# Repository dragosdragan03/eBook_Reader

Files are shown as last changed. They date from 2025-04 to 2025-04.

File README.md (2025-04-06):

# OpenBook ESP32-C6 Pin Connections

This document describes the pin connections between the ESP32-C6-WROOM-1 module and the various peripherals in the OpenBook e-reader project.

## Project Overview

The OpenBook is an electronic reader device based on the ESP32-C6 microcontroller. It features an e-paper display, SD card storage, environmental sensing, and robust power management for extended battery life. The device was designed to provide a power-efficient reading experience with modern wireless connectivity capabilities.

## Hardware Overview

### Main Controller – ESP32-C6-WROOM-1-N8
- **Architecture**: RISC-V (Single-Core)
- **Wireless**: Wi-Fi 6, Bluetooth 5 LE
- **Operating Voltage**: 3.3V
- **Interfaces**: SPI, I²C, UART, GPIO, USB

## Pin Assignments

| ESP32-C6 Pin | Function | Connected To | Description |
|---|---|---|---|
| 3 | RESET | Reset Button | System hardware reset |
| 4 | SS_SD | SD Card (pin 2) | SPI Slave Select for SD card |
| 6 | SCK | SD Card (pin 5) | SPI Clock signal |
| 7 | MOSI | SD Card (pin 3) | SPI Master Out Slave In |
| 8 | INT_RTC | RTC Module (pin 3) | Interrupt signal from RTC |
| 9 | 32KHz | RTC Module (pin 1) | 32KHz clock signal from RTC |
| 13 | USB_D- | USB-C Connector (pin 3) | USB Data Negative line |
| 14 | USB_D+ | USB-C Connector (pin 1) | USB Data Positive line |
| 15 | IO/BOOT | Boot Button | Boot mode selector button |
| 16 | RTC_RST | RTC Module (pin 4) | RTC reset control |
| 17 | I2C_PW | BME688 Sensor (pins 6, 8, 2) | Power control for environmental sensor |
| 19 | SDA | Multiple I²C devices | I²C Serial Data line (shared) |
| 20 | SCL | Multiple I²C devices | I²C Serial Clock line (shared) |
| 23 | IO/CHANGE | Change Button | Display/Mode change button |
| 27 | MISO | SD Card (pin 7) | SPI Master In Slave Out |

## Storage & Display

### SD Card
- **Interface**: SPI
- **Pins**:
  - CS (SS_SD): `GPIO 4`
  - MOSI: `GPIO 7`
  - MISO: `GPIO 27`
  - SCK: `GPIO 6`
- **Storage Capacity**: Supports up to 32GB SDHC

### E-Paper Display
- **Interface**: SPI (shared with SD)
- **Pins**:
  - CS (EPD_CS): `GPIO 10`
  - DC (EPD_DC): `GPIO 5`
  - RESET: `GPIO 23`
  - BUSY: `GPIO 3`
  - MOSI / SCK: shared with SD
- **Resolution**: 1404 × 1872 pixels (6.8")

### External NOR Flash (64MB)
- **Interface**: SPI (shared)
- **Pins**:
  - CS (FLASH_CS): `GPIO 12`
  - Shared: `MOSI`, `MISO`, `SCK`

## Timekeeping & Sensors

### RTC – DS3231SN
- **Interface**: I²C
- **Pins**:
  - SCL: `GPIO 20`
  - SDA: `GPIO 19`
  - INT: `GPIO 8`
  - 32KHz: `GPIO 9`
  - RESET: `GPIO 16`

### Environmental Sensor – BME688
- **Interface**: I²C (shared with RTC)
- **Supply Voltage**: 3.3V
- **Power Control Pin**: `GPIO 17`
- **Measurements**: Temperature, humidity, pressure, gas

## Power Management

### Power Supply
- **Input**: USB-C (5V)
- **Output**: 3.3V via LDO regulator
- **Battery**: 3.7V Li-Po, 2000mAh

### Charging Circuit
- **Function**: Li-Po battery charging
- **Charging Current**: 500mA
- **Battery Monitoring**:
  - Fuel gauge via I²C (MAX17048)
  - Pins: Same as shared I²C bus

## Communication & Interfaces

### USB-C Connector
- **Data Pins**:
  - USB_D-: `GPIO 13`
  - USB_D+: `GPIO 14`

### Qwiic / Stemma QT Connector
- **Interface**: I²C
- **Voltage**: 3.3V
- **Pins**: Shared with main I²C bus

## User Inputs
- **BOOT Button**: `GPIO 15`
- **RESET Button**: connected to pin 3
- **CHANGE Button**: `GPIO 23`

## Protection Features
- TVS diodes on USB data lines and SPI lines
- Reverse polarity protection
- ESD protection

## Components BOM (Bill of Materials)

| Component | Link | Estimated Price |
|---|---|---|
| CHG_LED | [KP-1608SURCK - Kingbright](https://www.snapeda.com/parts/KP-1608SURCK/Kingbright/view-part/?ref=search&t=LED%200603) | €0.15 |
| SJ1 | [Solder Jumpers](https://grabcad.com/library/solder-jumpers-1) | €0.05 |
| R3 | [R0402 1% 100K (RC0402FR-07100KL) - YAGEO](https://componentsearchengine.com/part-view/R0402%201%25%20100%20K%20(RC0402FR-07100KL)/YAGEO) | €0.01 |
| R1_PWRUSB | [R0402 1% 100K (RC0402FR-07100KL) - YAGEO](https://componentsearchengine.com/part-view/R0402%201%25%20100%20K%20(RC0402FR-07100KL)/YAGEO) | €0.01 |
| C1, C2, C4_USB, C6, C7, C8, C9, C10, C_DELAY | [CC0402MRX5R5BB106 - YAGEO](https://componentsearchengine.com/part-view/CC0402MRX5R5BB106/YAGEO) | €0.10 (per unit) |
| C3 | [Link 3D model](https://a360.co/4iZy6AA) | €0.12 |
| R1_PINH1, R2-PINH1, R_BOOT, R_CHARGE, R_CL1, R_RESET | [R0402 1% 100K (RC0402FR-07100KL) - YAGEO](https://componentsearchengine.com/part-view/R0402%201%25%20100%20K%20(RC0402FR-07100KL)/YAGEO) | €0.01 (per unit) |
| R1, R1-PINH, R2-PINH, R4, R5, R6, R7, R8, R9, R10 | [R0402 1% 100K (RC0402FR-07100KL) - YAGEO](https://componentsearchengine.com/part-view/R0402%201%25%20100%20K%20(RC0402FR-07100KL)/YAGEO) | €0.01 (per unit) |
| J4 | [Store Comet SRL](https://store.comet.srl.ro/Catalogue/Product/43497/) | €0.35 |
| R_CAPACITOR | [R0402 1% 100K (RC0402FR-07100KL) - YAGEO](https://componentsearchengine.com/part-view/R0402%201%25%20100%20K%20(RC0402FR-07100KL)/YAGEO) | €0.01 |
| C5 | [CC0402MRX5R5BB106 - YAGEO](https://componentsearchengine.com/part-view/CC0402MRX5R5BB106/YAGEO) | €0.10 |
| EPD_C1, EPD_C2, EPD_C5, EPD_C6, EPD_C7, EPD_C8, EPD_C9, EPD_C10, EPD_C11, EPD_C12 | [CC0402MRX5R5BB106 - YAGEO](https://componentsearchengine.com/part-view/CC0402MRX5R5BB106/YAGEO) | €0.10 (per unit) |
| R2 | [R0402 1% 100K (RC0402FR-07100KL) - YAGEO](https://componentsearchengine.com/part-view/R0402%201%25%20100%20K%20(RC0402FR-07100KL)/YAGEO) | €0.01 |
| R1_BAT | [R0402 1% 100K (RC0402FR-07100KL) - YAGEO](https://componentsearchengine.com/part-view/R0402%201%25%20100%20K%20(RC0402FR-07100KL)/YAGEO) | €0.01 |
| Q1, Q3 | [SI1308EDL-T1-GE3 - Vishay](https://componentsearchengine.com/part-view/SI1308EDL-T1-GE3/Vishay) | €0.45 (per unit) |
| R2_BAT | [R0402 1% 100K (RC0402FR-07100KL) - YAGEO](https://componentsearchengine.com/part-view/R0402%201%25%20100%20K%20(RC0402FR-07100KL)/YAGEO) | €0.01 |
| C1_BAT, C1_BAT1, C1_BAT2, C2_BAT, C5_USB | [CC0402MRX5R5BB106 - YAGEO](https://componentsearchengine.com/part-view/CC0402MRX5R5BB106/YAGEO) | €0.10 (per unit) |
| C4 | [CC0402MRX5R5BB106 - YAGEO](https://componentsearchengine.com/part-view/CC0402MRX5R5BB106/YAGEO) | €0.10 |
| R2-USB, R2-USB1 | [R0402 1% 100K (RC0402FR-07100KL) - YAGEO](https://componentsearchengine.com/part-view/R0402%201%25%20100%20K%20(RC0402FR-07100KL)/YAGEO) | €0.01 (per unit) |
| L1 | [744043680 - Wurth Elektronik](https://eu.mouser.com/ProductDetail/Wurth-Elektronik/744043680?qs=PGXP4M47uW6VkZq%252BkzjrHA%3D%3D) | €0.85 |
| IC1 | [BD5229G-TR - ROHM Semiconductor](https://componentsearchengine.com/part-view/BD5229G-TR/ROHM%20Semiconductor) | €1.20 |
| BOOT_BUTTON, CHANGE_BUTTON, RESET_BUTTON | [EVQP7L01P - Panasonic](https://www.snapeda.com/parts/EVQP7L01P/Panasonic/view-part/?ref=search&t=evqp7l) | €0.25 (per unit) |
| C10_SUPERCAP | [CPH3225A - Seiko Instruments](https://www.snapeda.com/api/url_track_click_mouser/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) | €2.50 |
| U3 | [DS3231SN - Analog Devices](https://www.snapeda.com/api/url_track_click_mouser/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) | €8.95 |
| U2 | [ESP32-C6-WROOM-1-N8 - Espressif](https://www.snapeda.com/parts/ESP32-C6-WROOM-1-N8/Espressif+Systems/view-part/?ref=eda) | €4.50 |
| PFMF.050.1 | [B72520T0350K062 - EPCOS-TDK](https://www.mouser.co.uk/ProductDetail/EPCOS-TDK/B72520T0350K062?qs=dEfas%2FXlABIszF52uu7vrg%3D%3D) | €0.65 |
| D2, D7 | [SD0805S020S1R0 - KYOCERA-AVX](https://eu.mouser.com/ProductDetail/KYOCERA-AVX/SD0805S020S1R0?qs=jCA%252BPfw4LHbpkAoSnwrdjw%3D%3D) | €0.30 (per unit) |
| SENSOR2 | [BME680 - Bosch](https://www.snapeda.com/parts/BME680/Bosch/view-part/?welcome=home) | €10.50 |
| MCP73831 | [MCP73831T-2ACI-OT - Microchip](https://www.digikey.ro/en/products/detail/microchip-technology/MCP73831T-2ACI-OT/964301) | €0.75 |
| J1 | [XC6220A331MR-G - Torex](https://componentsearchengine.com/part-view/XC6220A331MR-G/Torex) | €1.25 |
| U4 | [MAX17048G+T10 - Analog Devices](https://www.snapeda.com/api/url_track_click_mouser/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) | €3.80 |
| D3, D4, D5 | [MBR0530 - ON Semiconductor](https://www.snapeda.com/api/url_track_click_mouser/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) | €0.40 (per unit) |
| D6, D8, D9, D10, D11, D12 | [PGB1010603MR - Littelfuse](https://www.snapeda.com/api/url_track_click_mouser/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) | €0.30 (per unit) |
| J3 | [Model Link - DigiKey](https://www.digikey.ro/en/models/926710) | €1.05 |
| J2 | [USB4110-GF-A - GCT](https://componentsearchengine.com/part-view/USB4110-GF-A/GCT%20(GLOBAL%20CONNECTOR%20TECHNOLOGY)) | €0.95 |
| Q2 | [DMG2305UX-7 - Diodes Inc](https://componentsearchengine.com/part-view/DMG2305UX-7/Diodes%20Incorporated) | €0.55 |
| TP1, TP2, TP3, TP4, TP5, TP6, TP7, TP8, TP9, TP10, TP11, TP12, TP13, TP14, TP15, TP16, TP17 | [Test Points PCB](https://grabcad.com/library/test-points-printed-circuit-board-1) | €0.02 (per unit) |
| D1 | [USBLC6-2SC6Y - STMicroelectronics](https://www.snapeda.com/parts/USBLC6-2SC6Y/STMicroelectronics/view-part/?ref=eda) | €0.60 |
| U1 | [W25Q512JVEIQ - Winbond](https://www.snapeda.com/parts/W25Q512JVEIQ/Winbond+Electronics/view-part/?ref=eda) | €4.20 |
| IC4 | [XC6220A331MR-G - Torex](https://componentsearchengine.com/part-view/XC6220A331MR-G/Torex) | €1.25 |

## Circuit Block Diagram
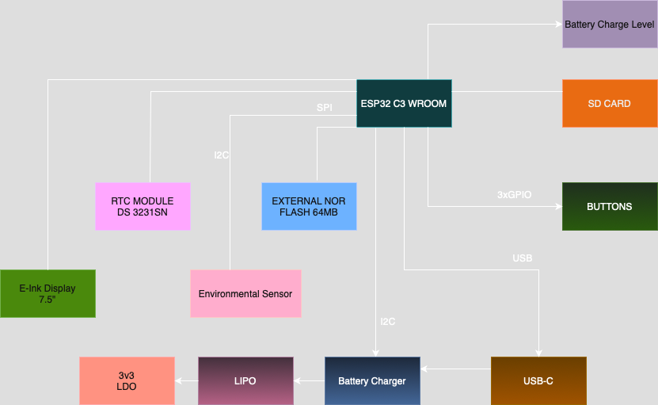
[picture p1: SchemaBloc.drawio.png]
Circuit Block Diagram


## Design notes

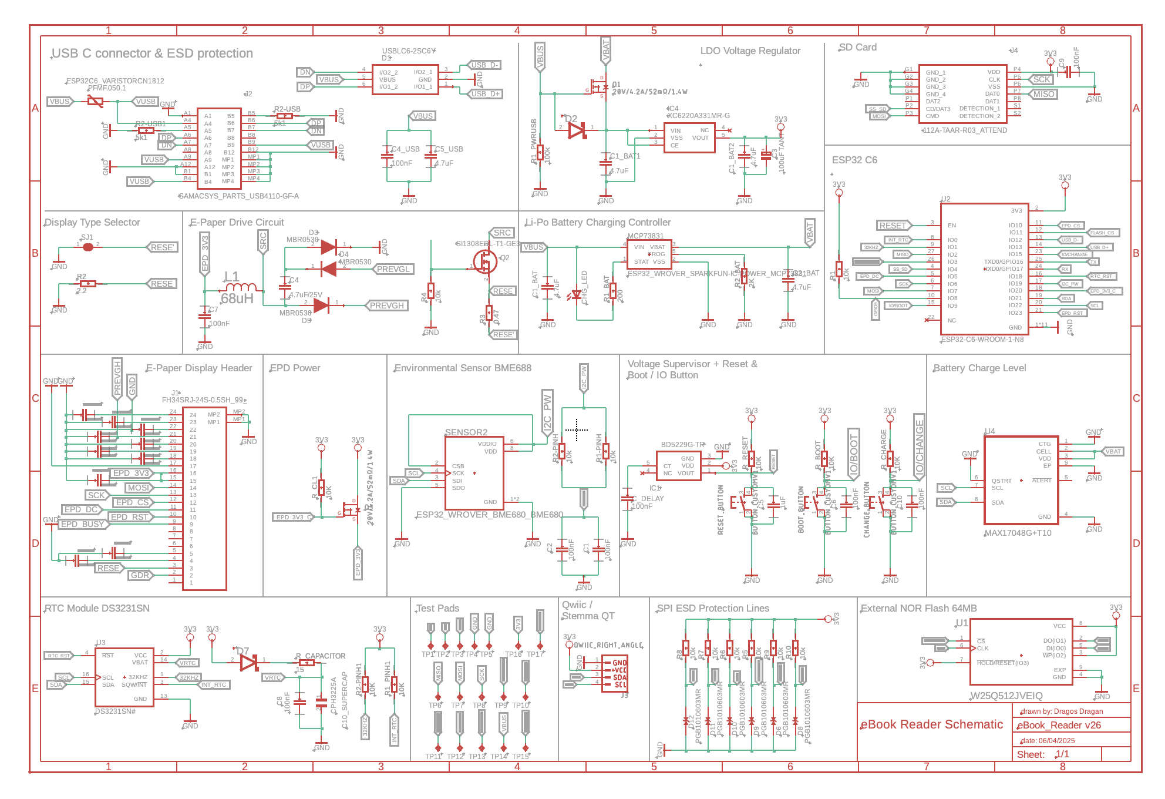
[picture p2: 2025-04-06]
Images/Schematic.png

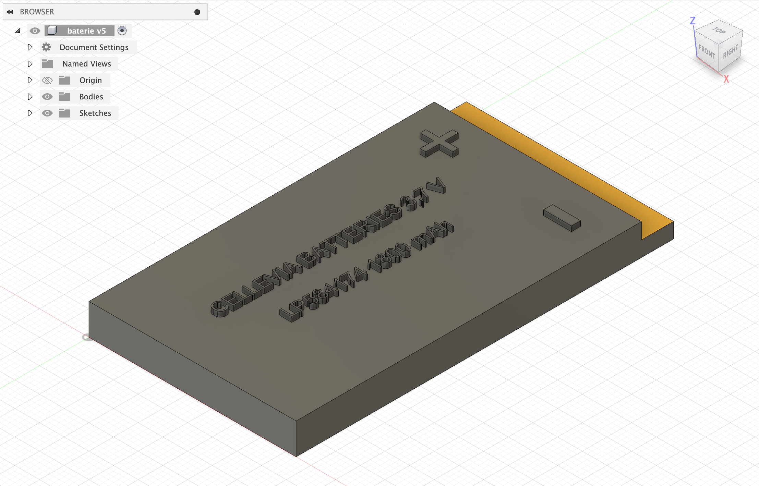
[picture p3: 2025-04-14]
Images/Battery.png

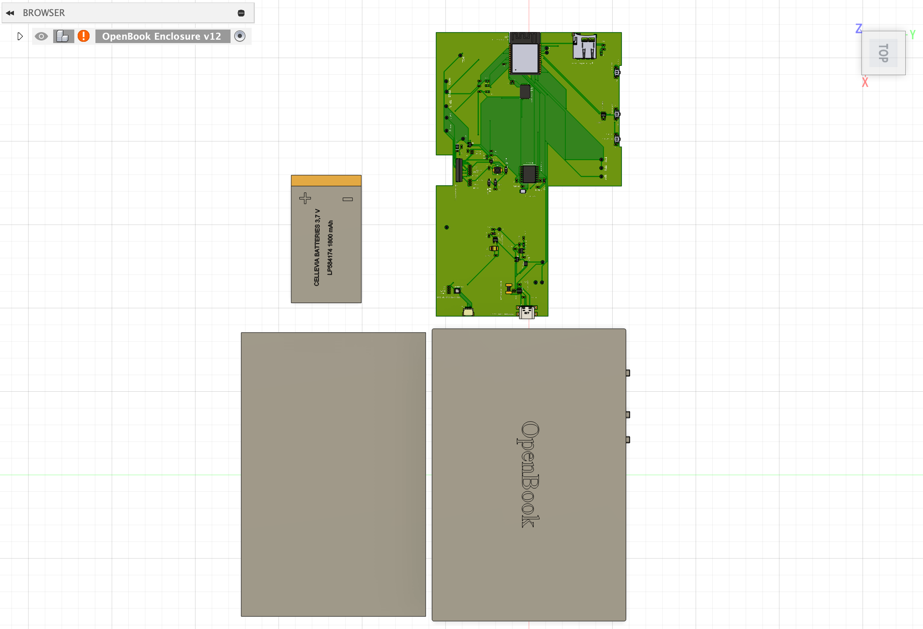
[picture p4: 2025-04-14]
Images/PCB+Box+Battery+Display_1.png

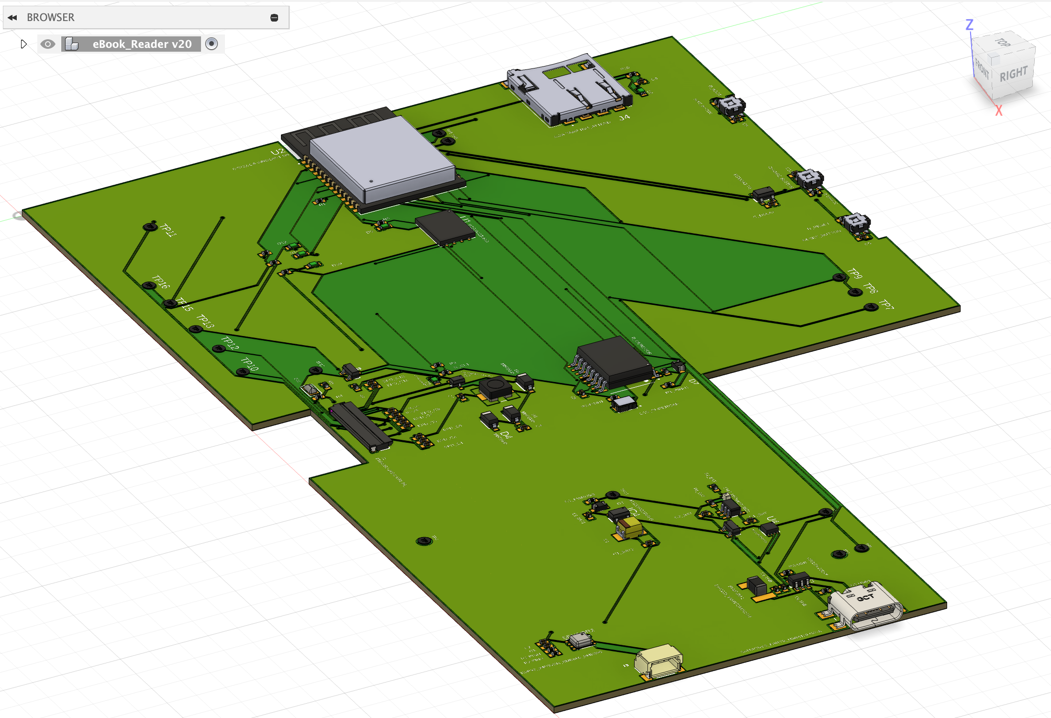
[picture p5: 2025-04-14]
Images/PCB.png

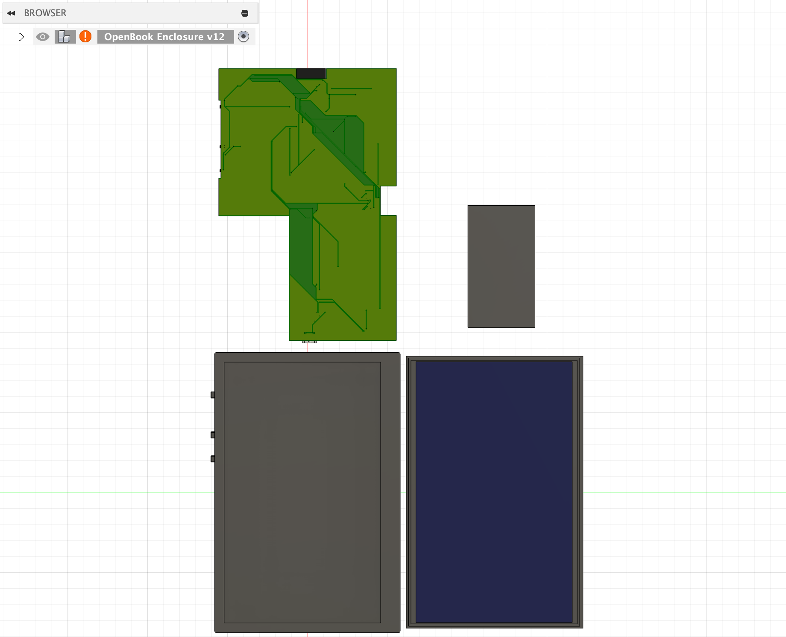
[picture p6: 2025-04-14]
Images/PCB+Box+Battery+Display_2.png

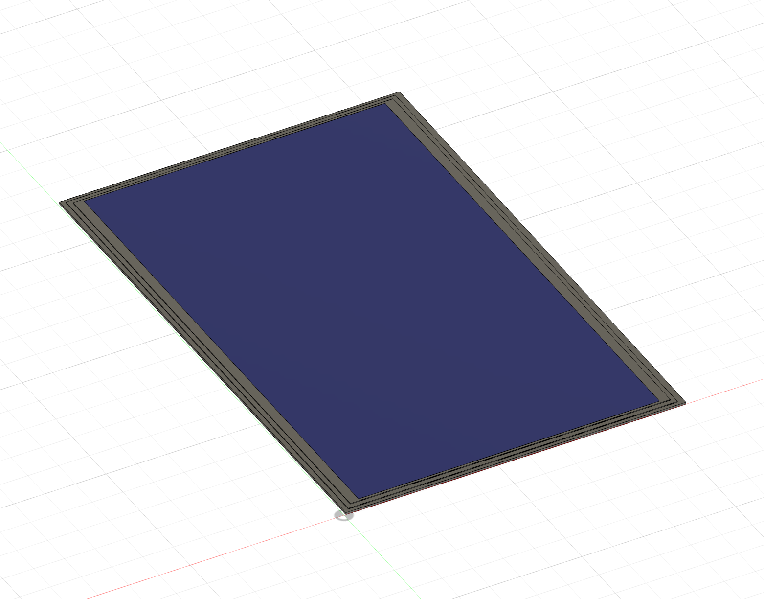
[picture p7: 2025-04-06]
Images/Display.png

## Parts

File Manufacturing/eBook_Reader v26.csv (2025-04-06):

Qty | Value | Device | Package | Parts | Description | ARROW_PART_NUMBER | ARROW_PRICE-STOCK | AVAILABILITY | CENTROID_NOT_SPECIFIED | CHECK_PRICES | COPYRIGHT | DATASHEET | DESCRIPTION | DIGIKEY_DESCRIPTION | DIGIKEY_PART_NUMBER | HEIGHT | LEAD_FREE | MANUFACTURER_NAME | MANUFACTURER_PART_NUMBER | MF | MFR_NAME | MOUSER_PART_NUMBER | MOUSER_PRICE-STOCK | MOUSER_TESTING_PART_NUMBER | MOUSER_TESTING_PRICE-STOCK | MP | MPN | PACKAGE | POPULARITY | PREFIX | PRICE | PROD_ID | PURCHASE-URL | ROHS | SNAPEDA_LINK | SPICEMODEL | SPICEPREFIX | TEMPERATURE_RANGE_HIGH | TEMPERATURE_RANGE_LOW | TP_SIGNAL_NAME | VALUE
1 |  | ADAFRUIT_LEDCHIP-LED0603 | ADAFRUIT_CHIP-LED0603 | CHG_LED | LED |  |  |  |  |  |  |  |  |  |  |  |  |  |  |  |  |  |  |  |  |  |  |  |  |  |  |  |  |  | https://www.snapeda.com/parts/KP-1608SURCK/Kingbright/view-part/?ref=search&t=LED%200603
1 |  | SJ | SJ | SJ1 | SMD solder JUMPER |  |  |  |  |  |  |  |  |  |  |  |  |  |  |  |  |  |  |  |  |  |  |  | 3 |  |  |  | https://grabcad.com/library/solder-jumpers-1
1 | 0.47 | ESP32_WROVER_EAGLE-LTSPICE_RR0402 | ESP32_WROVER_EAGLE-LTSPICE_R0402 | R3 | RESISTOR, European symbol |  |  |  |  |  |  |  |  |  |  |  |  |  |  |  |  |  |  |  |  |  |  |  |  |  |  |  | https://componentsearchengine.com/part-view/R0402%201%25%20100%20K%20(RC0402FR-07100KL)/YAGEO |  |  | NONE | R
1 | 100k | ESP32_WROVER_EAGLE-LTSPICE_RR0402 | ESP32_WROVER_EAGLE-LTSPICE_R0402 | R1_PWRUSB | RESISTOR, European symbol |  |  |  |  |  |  |  |  |  |  |  |  |  |  |  |  |  |  |  |  |  |  |  |  |  |  |  | https://componentsearchengine.com/part-view/R0402%201%25%20100%20K%20(RC0402FR-07100KL)/YAGEO |  |  | NONE | R
9 | 100nF | EAGLE-LTSPICE_CC0402 | EAGLE-LTSPICE_C0402 | C1, C2, C4_USB, C6, C7, C8, C9, C10, C_DELAY | CAPACITOR, European symbol |  |  |  |  |  |  |  |  |  |  |  |  |  |  |  |  |  |  |  |  |  |  |  |  |  |  |  | https://componentsearchengine.com/part-view/CC0402MRX5R5BB106/YAGEO |  |  | NONE | C
1 | 100uF TANT | RCL_CPOL-EUCT3528 | RCL_CT3528 | C3 | POLARIZED CAPACITOR, European symbol |  |  |  |  |  |  |  |  |  |  |  |  |  |  |  |  |  |  |  |  |  |  |  | 0 |  |  |  | https://a360.co/4iZy6AA |  |  |  | C
6 | 10K | ESP32_WROVER_EAGLE-LTSPICE_RR0402 | ESP32_WROVER_EAGLE-LTSPICE_R0402 | R1_PINH1, R2-PINH1, R_BOOT, R_CHARGE, R_CL1, R_RESET | RESISTOR, European symbol |  |  |  |  |  |  |  |  |  |  |  |  |  |  |  |  |  |  |  |  |  |  |  |  |  |  |  | https://componentsearchengine.com/part-view/R0402 1% 100 K (RC0402FR-07100KL)/YAGEO |  |  | NONE | R
10 | 10k | ESP32_WROVER_EAGLE-LTSPICE_RR0402 | ESP32_WROVER_EAGLE-LTSPICE_R0402 | R1, R1-PINH, R2-PINH, R4, R5, R6, R7, R8, R9, R10 | RESISTOR, European symbol |  |  |  |  |  |  |  |  |  |  |  |  |  |  |  |  |  |  |  |  |  |  |  |  |  |  |  | https://componentsearchengine.com/part-view/R0402 1% 100 K (RC0402FR-07100KL)/YAGEO |  |  | NONE | R
1 | 112A-TAAR-R03_ATTEND | 112A-TAAR-R03_ATTEND | 112ATAARR03ATTEND | J4 | Micro SD Card Socket, Push-Push Type, Top Mount, SMT, H=1.83mm, 10u |  |  |  |  |  |  |  | Micro SD Card Socket | Push-Push Type | Top Mount | SMT | H=1.83mm | 10u |  |  | 1.9mm |  | ATTEND | 112A-TAAR-R03 ATTEND |  |  |  |  |  |  |  |  | https://store.comet.srl.ro/Catalogue/Product/43497/
1 | 15 | ESP32_WROVER_EAGLE-LTSPICE_RR0402 | ESP32_WROVER_EAGLE-LTSPICE_R0402 | R_CAPACITOR | RESISTOR, European symbol |  |  |  |  |  |  |  |  |  |  |  |  |  |  |  |  |  |  |  |  |  |  |  |  |  |  |  | https://componentsearchengine.com/part-view/R0402%201%25%20100%20K%20(RC0402FR-07100KL)/YAGEO |  |  | NONE | R
1 | 1uF | EAGLE-LTSPICE_CC0402 | EAGLE-LTSPICE_C0402 | C5 | CAPACITOR, European symbol |  |  |  |  |  |  |  |  |  |  |  |  |  |  |  |  |  |  |  |  |  |  |  |  |  |  |  | https://componentsearchengine.com/part-view/CC0402MRX5R5BB106/YAGEO |  |  | NONE | C
10 | 1uF/50V | ESP32_WROVER_EAGLE-LTSPICE_CC0402 | ESP32_WROVER_EAGLE-LTSPICE_C0402 | EPD_C1, EPD_C2, EPD_C5, EPD_C6, EPD_C7, EPD_C8, EPD_C9, EPD_C10, EPD_C11, EPD_C12 | CAPACITOR, European symbol |  |  |  |  |  |  |  |  |  |  |  |  |  |  |  |  |  |  |  |  |  |  |  |  |  |  |  | https://componentsearchengine.com/part-view/CC0402MRX5R5BB106/YAGEO |  |  | NONE | C
1 | 2.2 | ESP32_WROVER_EAGLE-LTSPICE_RR0402 | ESP32_WROVER_EAGLE-LTSPICE_R0402 | R2 | RESISTOR, European symbol |  |  |  |  |  |  |  |  |  |  |  |  |  |  |  |  |  |  |  |  |  |  |  |  |  |  |  | https://componentsearchengine.com/part-view/R0402%201%25%20100%20K%20(RC0402FR-07100KL)/YAGEO |  |  | NONE | R
1 | 200 | ESP32_WROVER_EAGLE-LTSPICE_RR0402 | ESP32_WROVER_EAGLE-LTSPICE_R0402 | R1_BAT | RESISTOR, European symbol |  |  |  |  |  |  |  |  |  |  |  |  |  |  |  |  |  |  |  |  |  |  |  |  |  |  |  | https://componentsearchengine.com/part-view/R0402%201%25%20100%20K%20(RC0402FR-07100KL)/YAGEO |  |  | NONE | R
2 | 20V/4.2A/52mΩ/1.4W | ESP32_WROVER_SPARKFUN-DISCRETESEMI_MOSFET_PCH-DMG2305UX-7 | ESP32_WROVER_SPARKFUN-DISCRETESEMI_SOT23-3 | Q1, Q3 | P-channel MOSFETs |  |  |  |  |  |  |  |  |  |  |  |  |  |  |  |  |  |  |  |  |  |  |  |  |  |  | TRAN-14388 | https://componentsearchengine.com/part-view/SI1308EDL-T1-GE3/Vishay |  |  |  |  |  |  |  | 20V/4.2A/52mΩ/1.4W
1 | 2K | ESP32_WROVER_EAGLE-LTSPICE_RR0402 | ESP32_WROVER_EAGLE-LTSPICE_R0402 | R2_BAT | RESISTOR, European symbol |  |  |  |  |  |  |  |  |  |  |  |  |  |  |  |  |  |  |  |  |  |  |  |  |  |  |  | https://componentsearchengine.com/part-view/R0402%201%25%20100%20K%20(RC0402FR-07100KL)/YAGEO |  |  | NONE | R
5 | 4.7uF | EAGLE-LTSPICE_CC0402 | EAGLE-LTSPICE_C0402 | C1_BAT, C1_BAT1, C1_BAT2, C2_BAT, C5_USB | CAPACITOR, European symbol |  |  |  |  |  |  |  |  |  |  |  |  |  |  |  |  |  |  |  |  |  |  |  |  |  |  |  | https://componentsearchengine.com/part-view/CC0402MRX5R5BB106/YAGEO |  |  | NONE | C
1 | 4.7uF/25V | EAGLE-LTSPICE_CC0402 | EAGLE-LTSPICE_C0402 | C4 | CAPACITOR, European symbol |  |  |  |  |  |  |  |  |  |  |  |  |  |  |  |  |  |  |  |  |  |  |  |  |  |  |  | https://componentsearchengine.com/part-view/CC0402MRX5R5BB106/YAGEO |  |  | NONE | C
2 | 5k1 | ESP32_WROVER_EAGLE-LTSPICE_RR0402 | ESP32_WROVER_EAGLE-LTSPICE_R0402 | R2-USB, R2-USB1 | RESISTOR, European symbol |  |  |  |  |  |  |  |  |  |  |  |  |  |  |  |  |  |  |  |  |  |  |  |  |  |  |  | https://componentsearchengine.com/part-view/R0402%201%25%20100%20K%20(RC0402FR-07100KL)/YAGEO |  |  | NONE | R
1 | 68uH | 744043680IND_4828-WE-TPC_WRE | IND_4828-WE-TPC_WRE | L1 |  |  |  |  |  |  | Copyright (C) 2024 Ultra Librarian. All rights reserved. |  |  |  |  |  |  |  | 744043680 |  | Wurth Electronics |  |  |  |  |  |  |  |  |  |  |  | https://eu.mouser.com/ProductDetail/Wurth-Elektronik/744043680?qs=PGXP4M47uW6VkZq%252BkzjrHA%3D%3D
1 | BD5229G-TR | BD5229G-TR | SOT95P280X125-5N | IC1 | Voltage Detector with Adjustable Delay Time: CMOS processes are utilized to develop high precision, low current consumption CMOS reset ICs that allow arbitrary setting of the delay time. The extensive lineup includes both Nch Open Drain and CMOS output types in a wide range of detection voltages (from 2.3V to 6.0V, in 0.1V steps), enabling selection of the ideal solution based on customer requirements. In addition, the entire series is of course both lead-free and RoHS-compliant. |  |  |  |  |  |  |  | Voltage Detector with Adjustable Delay Time: CMOS processes are utilized to develop high precision | low current consumption CMOS reset ICs that allow arbitrary setting of the delay time. The extensive lineup includes both Nch Open Drain and CMOS output types in a wide range of detection voltages (from 2.3V to 6.0V | in 0.1V steps) | enabling selection of the ideal solution based on customer requirements. In addition | the entire series is of course both lead-free and RoHS-compliant. |  |  | 1.25mm |  | ROHM Semiconductor | BD5229G-TR |  |  | 755-BD5229G-TR | https://www.mouser.co.uk/ProductDetail/ROHM-Semiconductor/BD5229G-TR?qs=4kLU8WoGk0vvnhrrYwdszw%3D%3D |  |  |  |  |  | https://componentsearchengine.com/part-view/BD5229G-TR/ROHM%20Semiconductor
3 | BUTTON_CUSYOMV1 | BUTTON_CUSYOMV1 | MYBUTTON | BOOT_BUTTON, CHANGE_BUTTON, RESET_BUTTON |  |  |  |  |  |  |  |  |  |  |  |  |  |  |  |  |  |  |  |  |  |  |  |  |  |  |  |  | https://www.snapeda.com/parts/EVQP7L01P/Panasonic/view-part/?ref=search&t=evqp7l
1 | CPH3225A | CPH3225A | CAPCP3225X100N | C10_SUPERCAP | Cap 0.011F 3.3V 1210 Flat Check availability |  |  | Not in stock |  | https://www.snapeda.com/parts/CPH3225A/Seiko+Instruments/view-part/?ref=eda |  |  | 11 mF (EDLC) Supercapacitor 3.3 V 1210 (3225 Metric) - - |  |  |  |  |  |  | Seiko Instruments |  |  |  |  |  | CPH3225A |  | 1210 Seiko |  |  | None |  | https://www.snapeda.com/api/url_track_click_mouser/?unipart_id=562593&manufacturer=Seiko Instruments&part_name=CPH3225A&search_term=None |  | https://www.snapeda.com/parts/CPH3225A/Seiko+Instruments/view-part/?ref=snap
1 | DS3231SN# | DS3231SN# | SOIC127P1032X265-16N | U3 | Real Time Clock Serial 16-Pin SOIC W T/R Check availability |  |  | In Stock |  | https://www.snapeda.com/parts/DS3231SN%23/Analog+Devices/view-part/?ref=eda |  |  | Extremely Accurate I²C-Integrated RTC/TCXO/Crystal |  |  |  |  |  |  | Analog Devices |  |  |  |  |  | DS3231SN# |  | SOIC-16 Maxim |  |  | None |  | https://www.snapeda.com/api/url_track_click_mouser/?unipart_id=99048&manufacturer=Analog Devices&part_name=DS3231SN#&search_term=None |  | https://www.snapeda.com/parts/DS3231SN%23/Analog+Devices/view-part/?ref=snap
1 | ESP32-C6-WROOM-1-N8 | ESP32-C6-WROOM-1-N8 | XCVR_ESP32-C6-WROOM-1-N8 | U2 | Check availability |  |  | In Stock |  | https://www.snapeda.com/parts/ESP32-C6-WROOM-1-N8/Espressif+Systems/view-part/?ref=eda |  |  | Multiprotocol Modules ESP32-C6 module | Wi-Fi 6 in 2.4 GHz band | Bluetooth 5 | Zigbee 3.0 and Thread. ESP34-WROOM Compatible - ENGINEERING SAMPLE |  |  |  |  |  |  | Espressif Systems |  |  |  |  |  | ESP32-C6-WROOM-1-N8 |  | None |  | https://www.snapeda.com/parts/ESP32-C6-WROOM-1-N8/Espressif+Systems/view-part/?ref=eda | None |  |  |  | https://www.snapeda.com/parts/ESP32-C6-WROOM-1-N8/Espressif+Systems/view-part/?ref=snap
1 | ESP32C6_VARISTORCN1812 | ESP32C6_VARISTORCN1812 | ESP32C6_VARISTOR_CT/CN1812 | PFMF.050.1 | VARISTOR |  |  |  |  |  |  |  |  |  |  |  |  |  |  |  |  |  |  |  |  |  |  |  | 0 |  |  |  | https://www.mouser.co.uk/ProductDetail/EPCOS-TDK/B72520T0350K062?qs=dEfas%2FXlABIszF52uu7vrg%3D%3D
2 | ESP32_WROVER_AVX---SD0805S020S1R0_AVX_SD0805S020S1R0_0_0AVX_SD0805S020S1R0_0_0 | ESP32_WROVER_AVX---SD0805S020S1R0_AVX_SD0805S020S1R0_0_0AVX_SD0805S020S1R0_0_0 | ESP32_WROVER_AVX---SD0805S020S1R0_AVX_SD0805S020S1R0_0 | D2, D7 | Schottky Barrier Rectifier Diode |  |  |  | No |  |  | http://datasheets.avx.com/schottky.pdf |  | DIODE SCHOTTKY 20V 1A 0805 | 478-7800-1-ND |  | yes |  |  | AVX |  | 581-SD0805S020S1R0 |  |  |  |  |  | 0805 (2012 metric) |  | D |  |  | https://eu.mouser.com/ProductDetail/KYOCERA-AVX/SD0805S020S1R0?qs=jCA%252BPfw4LHbpkAoSnwrdjw%3D%3D | yes |  |  |  | +125°C | -55°C
1 | ESP32_WROVER_BME680_BME680 | ESP32_WROVER_BME680_BME680 | ESP32_WROVER_BME680_PSON80P300X300X100-8N | SENSOR2 | Integrated Environmental Unit |  |  | Unavailable |  |  |  |  | Integrated Environmental Unit |  |  |  |  |  |  | Bosch Sensortec |  |  |  |  |  | BME680 |  | LGA-8 Bosch Tools |  |  | None |  | https://www.snapeda.com/parts/BME680/Bosch/view-part/?welcome=home
1 | ESP32_WROVER_SPARKFUN-IC-POWER_MCP73831 | ESP32_WROVER_SPARKFUN-IC-POWER_MCP73831 | ESP32_WROVER_SPARKFUN-IC-POWER_SOT23-5 | MCP73831 | MCP73831T Li-Ion, Li-Pol Controller |  |  |  |  |  |  |  |  |  |  |  |  |  |  |  |  |  |  |  |  |  |  |  |  |  |  | IC-09995 | https://www.digikey.ro/en/products/detail/microchip-technology/MCP73831T-2ACI-OT/964301
1 | FH34SRJ-24S-0.5SH_99_ | FH34SRJ-24S-0.5SH_99_ | FH34SRJ24S05SH99 | J1 | (0.50mm) Surface Mount, Right Angle |  |  |  |  |  |  |  | 24 Position FFC | FPC Connector Contacts | (0.50mm) Surface Mount | Right Angle |  |  | 1.1mm |  | Hirose | FH34SRJ-24S-0.5SH(99) |  |  | 798-FH34SRJ24S05SH99 | https://www.mouser.co.uk/ProductDetail/Hirose-Connector/FH34SRJ-24S-0.5SH99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 |  |  |  |  |  |  | https://componentsearchengine.com/part-view/XC6220A331MR-G/Torex
1 | MAX17048G+T10 | MAX17048G+T10 | SON50P200X200X80-9N | U4 | Check availability |  |  | In Stock |  | https://www.snapeda.com/parts/MAX17048G+T10/Analog+Devices/view-part/?ref=eda |  |  | 3µA 1-Cell/2-Cell Fuel Gauge with ModelGauge |  |  |  |  |  |  | Analog Devices |  |  |  |  |  | MAX17048G+T10 |  | TDFN-8 Maxim |  |  | None |  | https://www.snapeda.com/api/url_track_click_mouser/?unipart_id=329239&manufacturer=Analog Devices&part_name=MAX17048G+T10&search_term=None |  | https://www.snapeda.com/parts/MAX17048G+T10/Analog+Devices/view-part/?ref=snap
3 | MBR0530 | MBR0530 | SOD3716X135N | D3, D4, D5 | ON SEMICONDUCTOR - MBR0530 - DIODE, SCHOTTKY, 0.5A, 30V, SOD-123 |  |  | In Stock |  | https://www.snapeda.com/parts/MBR0530/Onsemi/view-part/?ref=eda |  |  | Diode Schottky 30 V 500mA Surface Mount SOD-123 |  |  |  |  |  |  | ON Semiconductor |  |  |  |  |  | MBR0530 |  | SOD-123-2 ON Semiconductor |  |  | None |  | https://www.snapeda.com/api/url_track_click_mouser/?unipart_id=179458&manufacturer=ON Semiconductor&part_name=MBR0530&search_term=None |  | https://www.snapeda.com/parts/MBR0530/Onsemi/view-part/?ref=snap
6 | PGB1010603MR | PGB1010603MR | DIOC1608X36N | D6, D8, D9, D10, D11, D12 | Check availability |  |  | In Stock |  | https://www.snapeda.com/parts/PGB1010603MR/Littelfuse/view-part/?ref=eda |  |  | 150V (Typ) Clamp - Ipp Tvs Diode Surface Mount 0603 (1608 Metric) |  |  |  |  |  |  | Littelfuse Inc. |  |  |  |  |  | PGB1010603MR |  | 0603 Littelfuse Inc. |  |  | None |  | https://www.snapeda.com/api/url_track_click_mouser/?unipart_id=5659453&manufacturer=Littelfuse Inc.&part_name=PGB1010603MR&search_term=None |  | https://www.snapeda.com/parts/PGB1010603MR/Littelfuse/view-part/?ref=snap
1 | QWIIC_RIGHT_ANGLE | QWIIC_CONNECTORJS-1MM | JST04_1MM_RA | J3 | SparkFun I2C Standard Qwiic Connector |  |  |  |  |  |  |  |  |  |  |  |  |  |  |  |  |  |  |  |  |  |  |  |  |  |  | CONN-13694 | https://www.digikey.ro/en/models/926710 |  |  |  |  |  |  |  | QWIIC_RIGHT_ANGLE
1 | SAMACSYS_PARTS_USB4110-GF-A | SAMACSYS_PARTS_USB4110-GF-A | SAMACSYS_PARTS_USB4110GFA | J2 | CONN USB 2.0 TYPE-C R/A SMT |  |  |  |  |  |  |  | CONN USB 2.0 TYPE-C R/A SMT |  |  | 3.26mm |  | GCT (GLOBAL CONNECTOR TECHNOLOGY) | USB4110-GF-A |  |  | 640-USB4110-GF-A | https://www.mouser.co.uk/ProductDetail/GCT/USB4110-GF-A?qs=KUoIvG%2F9IlYiZvIXQjyJeA%3D%3D |  |  |  |  |  |  |  |  |  | https://componentsearchengine.com/part-view/USB4110-GF-A/GCT%20(GLOBAL%20CONNECTOR%20TECHNOLOGY)
1 | SI1308EDL-T1-GE3 | SI1308EDL-T1-GE3 | SOT65P210X110-3N | Q2 | MOSFET N-Ch 30V 1.5A TrenchFET SC70 Vishay Si1308EDL-T1-GE3 N-channel MOSFET Transistor, 1.5 A, 30 V, 3-Pin SC-70 |  |  | In Stock |  | https://www.snapeda.com/parts/SI1308EDL-T1-GE3/Vishay+Siliconix/view-part/?ref=eda |  |  | Si1308EDL-T1-GE3 N-channel MOSFET Transistor | 1.5 A | 30 V | 3-Pin SC-70 | Siliconix / Vishay SI1308EDL-T1-GE3 |  |  |  |  |  |  | Vishay Siliconix |  |  |  |  |  | SI1308EDL-T1-GE3 |  | SOT-323 Vishay Semiconductor |  | https://componentsearchengine.com/part-view/DMG2305UX-7/Diodes%20Incorporated | None |  | https://www.snapeda.com/api/url_track_click_mouser/?unipart_id=274603&manufacturer=Vishay Siliconix&part_name=SI1308EDL-T1-GE3&search_term=None |  | https://www.snapeda.com/parts/SI1308EDL-T1-GE3/Vishay+Siliconix/view-part/?ref=snap
17 | TPTP20R | TPTP20R | TP20R | TP1, TP2, TP3, TP4, TP5, TP6, TP7, TP8, TP9, TP10, TP11, TP12, TP13, TP14, TP15, TP16, TP17 | Test pad |  |  |  |  |  |  |  |  |  |  |  |  |  |  |  |  |  |  |  |  |  |  |  | 2 |  |  |  | https://grabcad.com/library/test-points-printed-circuit-board-1
1 | USBLC6-2SC6Y | USBLC6-2SC6Y | SOT95P280X145-6N | D1 | Low Cap. ESD Protection Auto SOT-23-6 STMicroelectronics USBLC6-2SC6Y, Dual Uni-Directional TVS Diode Array, 6-Pin SOT-23 |  |  | In Stock |  | https://www.snapeda.com/parts/USBLC6-2SC6Y/STMicroelectronics/view-part/?ref=eda |  |  | 17V Clamp 5A (8/20µs) Ipp Tvs Diode Surface Mount SOT-23-6 |  |  |  |  |  |  | STMicroelectronics |  |  |  |  |  | USBLC6-2SC6Y |  | SOT-23-6 STMicroelectronics |  |  | None |  | https://www.snapeda.com/parts/USBLC6-2SC6Y/STMicroelectronics/view-part/?ref=eda |  | https://www.snapeda.com/parts/USBLC6-2SC6Y/STMicroelectronics/view-part/?ref=snap
1 | W25Q512JVEIQ | W25Q512JVEIQ | SON127P600X800X80-9N | U1 | Check availability |  |  | In Stock |  | https://www.snapeda.com/parts/W25Q512JVEIQ/Winbond+Electronics/view-part/?ref=eda |  |  | FLASH - NOR Memory IC 512Mb (64M x 8) SPI - Quad I/O 133 MHz 8-WSON (8x6) |  |  |  |  |  |  | Winbond Electronics |  |  |  |  |  | W25Q512JVEIQ |  | Package |  |  | None |  | https://www.snapeda.com/parts/W25Q512JVEIQ/Winbond+Electronics/view-part/?ref=eda |  | https://www.snapeda.com/parts/W25Q512JVEIQ/Winbond+Electronics/view-part/?ref=snap
1 | XC6220A331MR-G | XC6220A331MR-G | SOT95P280X120-5N | IC4 | LDO Voltage Regulators |  |  |  |  |  |  |  | LDO Voltage Regulators |  |  | 1.2mm |  | Torex | XC6220A331MR-G |  |  | 865-XC6220A331MR-G | https://www.mouser.co.uk/ProductDetail/Torex-Semiconductor/XC6220A331MR-G?qs=AsjdqWjXhJ8ZSWznL1J0gg%3D%3D |  |  |  |  |  |  |  |  |  | https://componentsearchengine.com/part-view/XC6220A331MR-G/Torex

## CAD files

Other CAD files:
Mechanical/eBook_Reader.f3z

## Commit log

2025-04-06 3D components + Readme + PCB
    [PnP_eBook_Reader v26_front.csv, eBook_Reader v26.csv]
2025-04-06 changed schematic
2025-04-06 added in readme diagram + bom
2025-04-14 resolved issues
    [eBook_Reader.f3z]
